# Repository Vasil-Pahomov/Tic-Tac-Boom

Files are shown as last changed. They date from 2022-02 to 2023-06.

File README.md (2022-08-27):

# Tic-Tac-Boom
Аппаратная реализация игры Тик Так Бумм. Дополнительно реализован таймер на 1 минуту, полезный в некоторых играх, например "Скажи иначе" (Alias)

# Использование
Короткое нажатие кнопки запускает таймер, длинное - "бомбу" для Тик Так Бумм.

# Схема
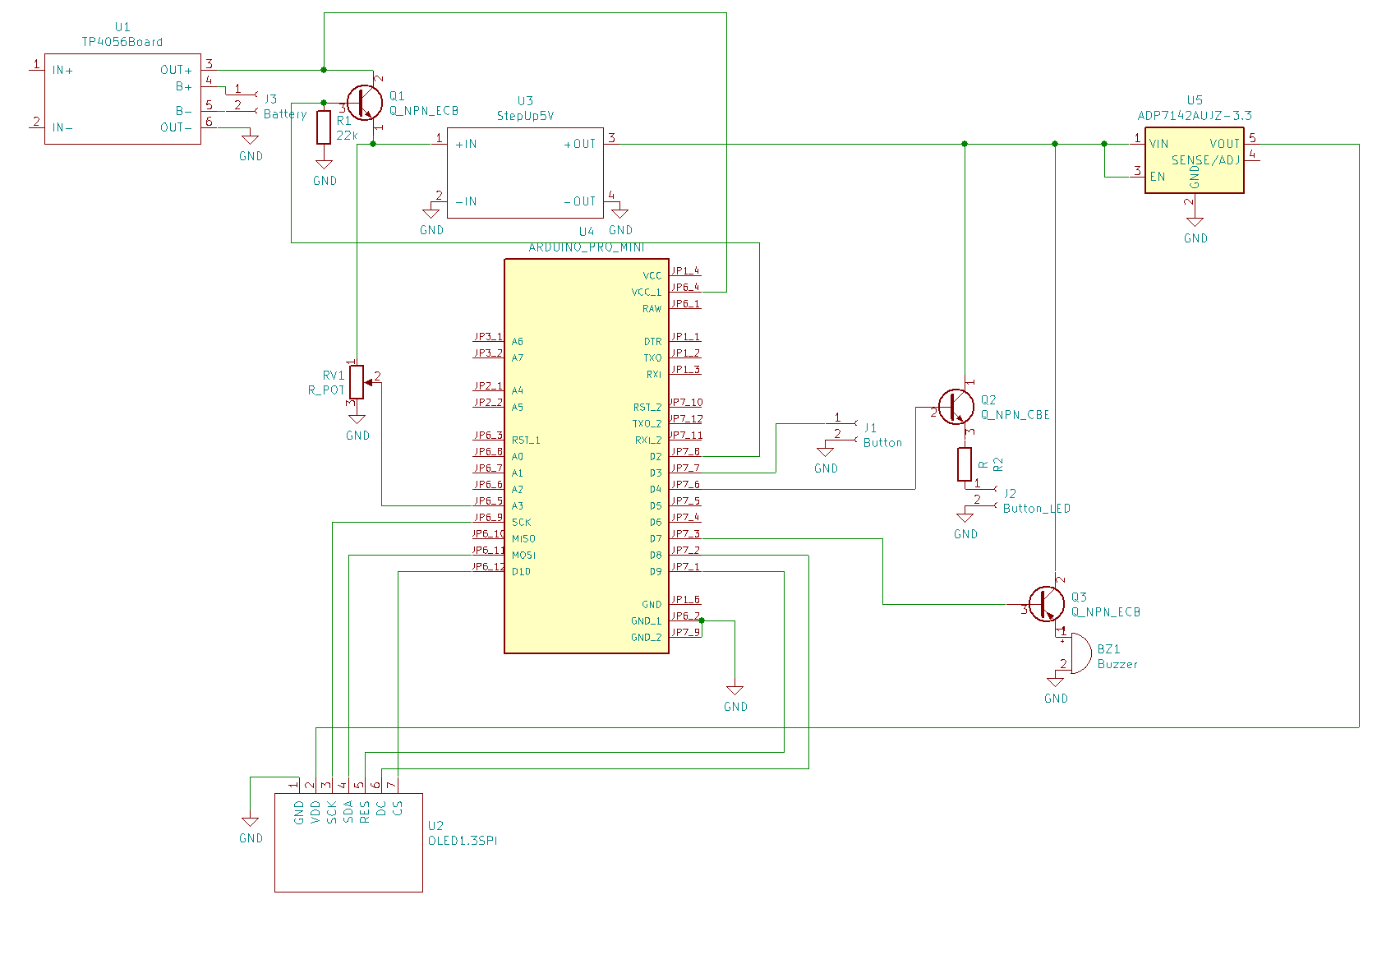
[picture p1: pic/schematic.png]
схема


# Компоненты
## Контроллер
В проекте использована "китайская" плата Arduino Pro Mini, переведённая в режим тактирования от внутреннего RC-генератора (отличная статья: https://tsibrov.blogspot.com/2018/12/arduino-internal-rc.html). Из платы нужно выпаять стабилизатор напряжения и светодиод питания (https://alexgyver.ru/lessons/power-sleep/)
Можно просто выпаять стабилизатор и светодиод, но тогда в режиме ожидания аккумулятор будет выжираться гораздо быстрее.
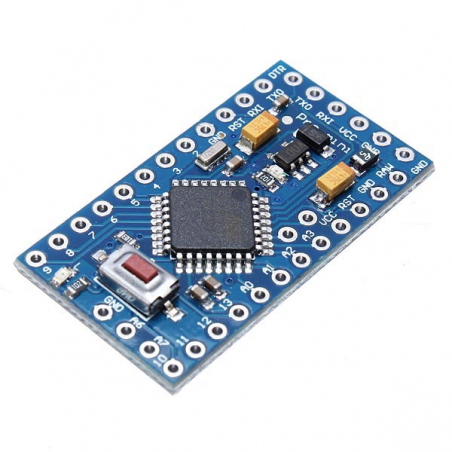
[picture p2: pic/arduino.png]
контроллер


## Экран
Широко распространённый OLED-экран 1.3 дюйма 128x64 точки с интерфейсом SPI.
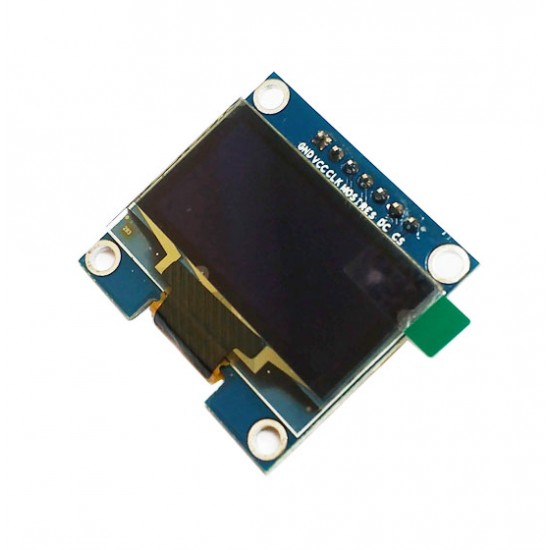
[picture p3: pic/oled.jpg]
экран


## Плата защиты/заряда аккумулятора
"Народная" плата на TP4056
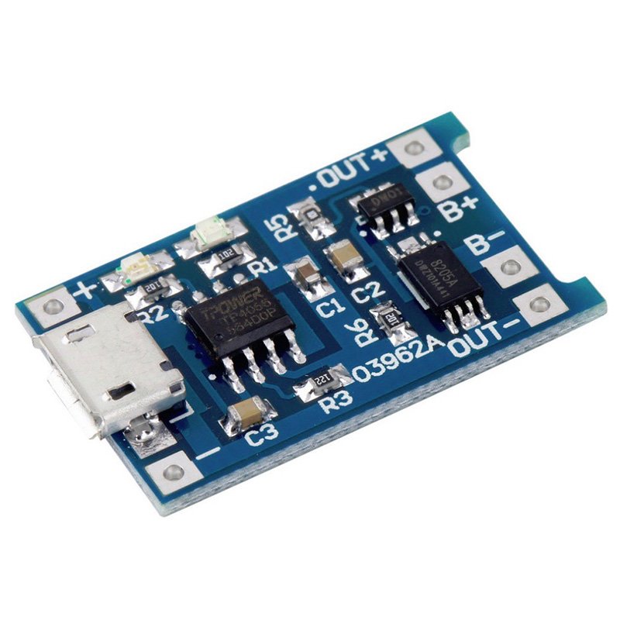
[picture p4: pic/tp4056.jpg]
защита/заряд


## Плата повышающего преобразователя напряжения до 5V
Лежала в старых запасах. Из платы пришлось выпаять разъём USB и подрезать её. Сейчас есть более миниатюрные варианты, можно использовать их.
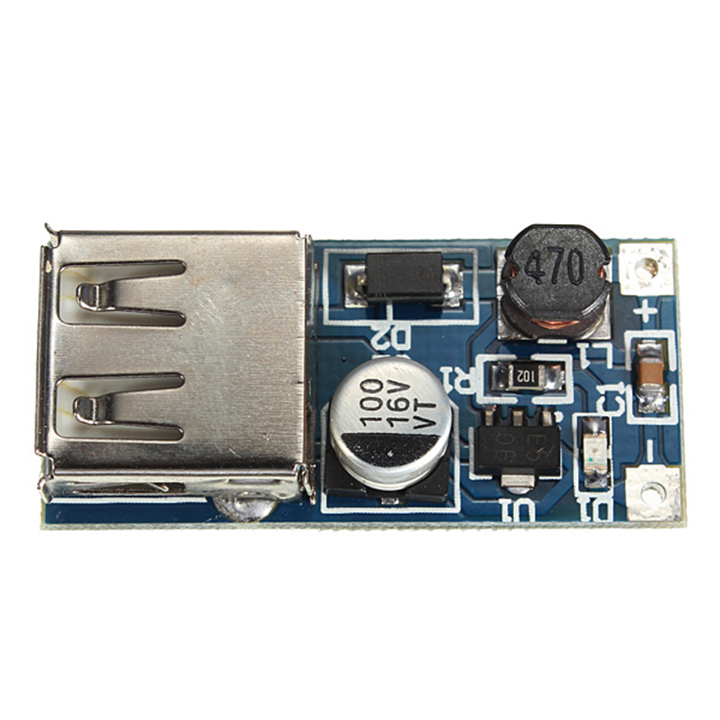
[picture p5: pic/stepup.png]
повышайка


## Кнопка, динамик, остальные элементы
Могут быть любыми. Кнопку лучше искать со встроенным светодиодом - выгдядит эффектнее

# Конструкция
Корпус сделал из двух половинок - каждая из отрезанной от пластиковой бутылки части. Внутри жёсткий каркас образуют круглая плата и вставленный перпендикулярно круг из 3мм оргстекла с вырезами под кнопку и динамик. Кнопка вклеена в каркас, т.к. корпус слишком мягкий и проседал бы при нажатиях.
Не могу сказать, что очень удачная, поэтому не буду рекомендовать к повторению. Проект kicad со схемой и печатной платой есть в папке kicad, можно взять на за основу. 
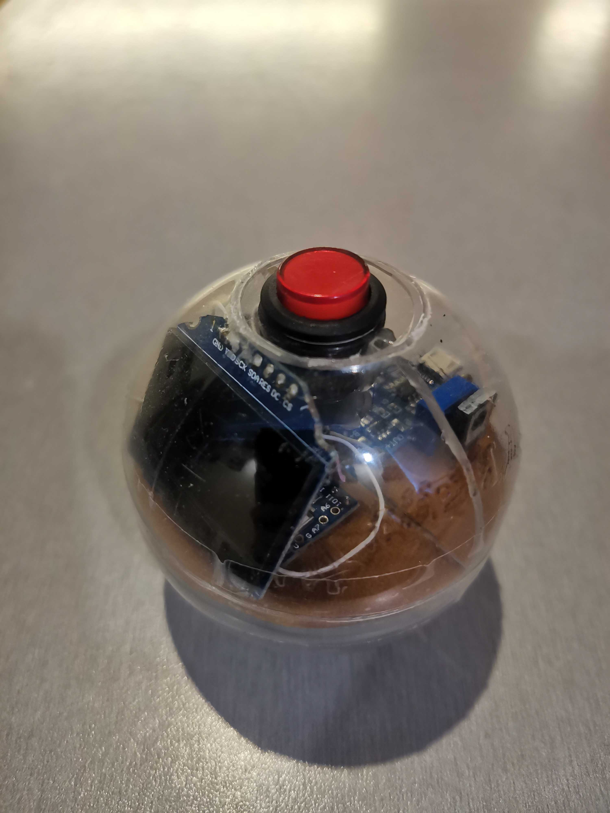
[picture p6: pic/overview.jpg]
общий вид


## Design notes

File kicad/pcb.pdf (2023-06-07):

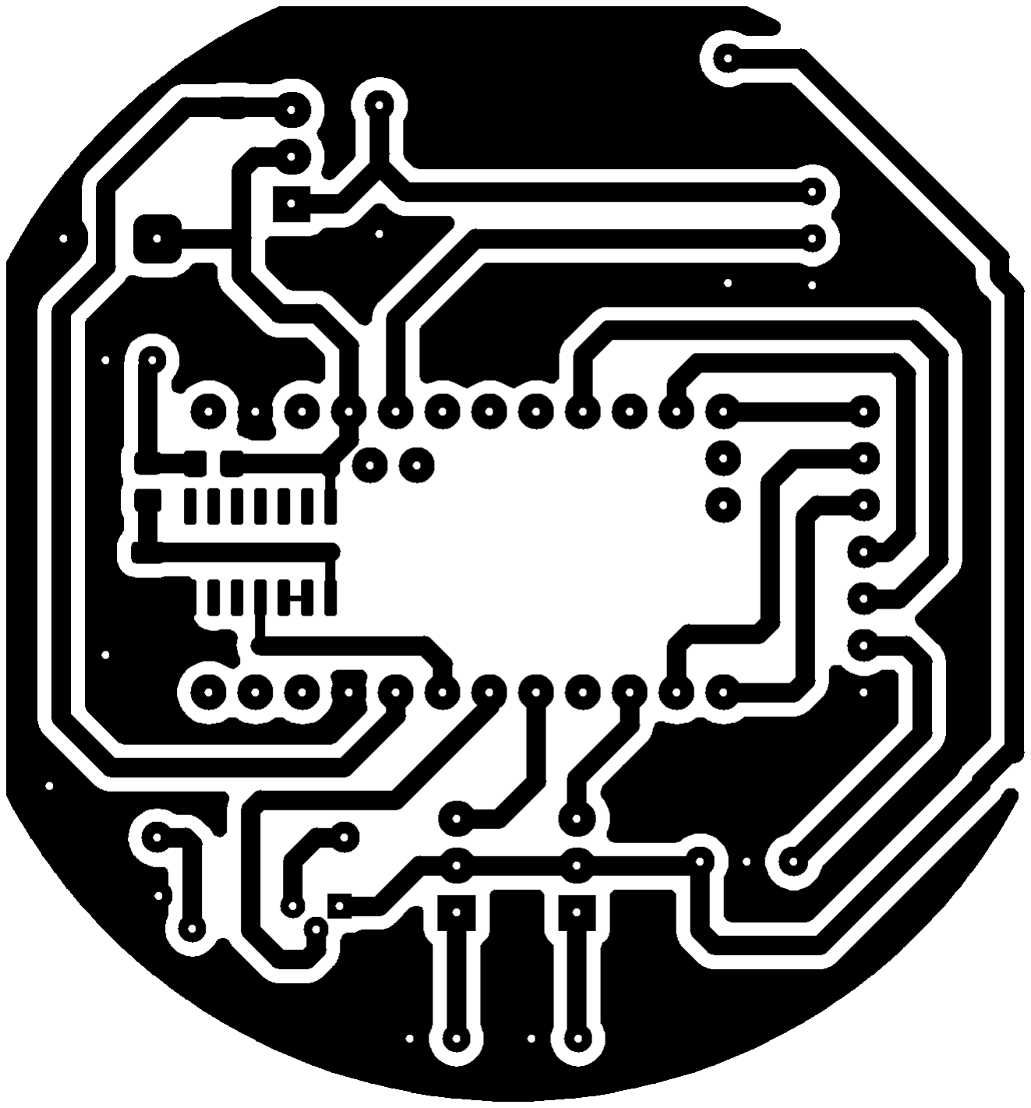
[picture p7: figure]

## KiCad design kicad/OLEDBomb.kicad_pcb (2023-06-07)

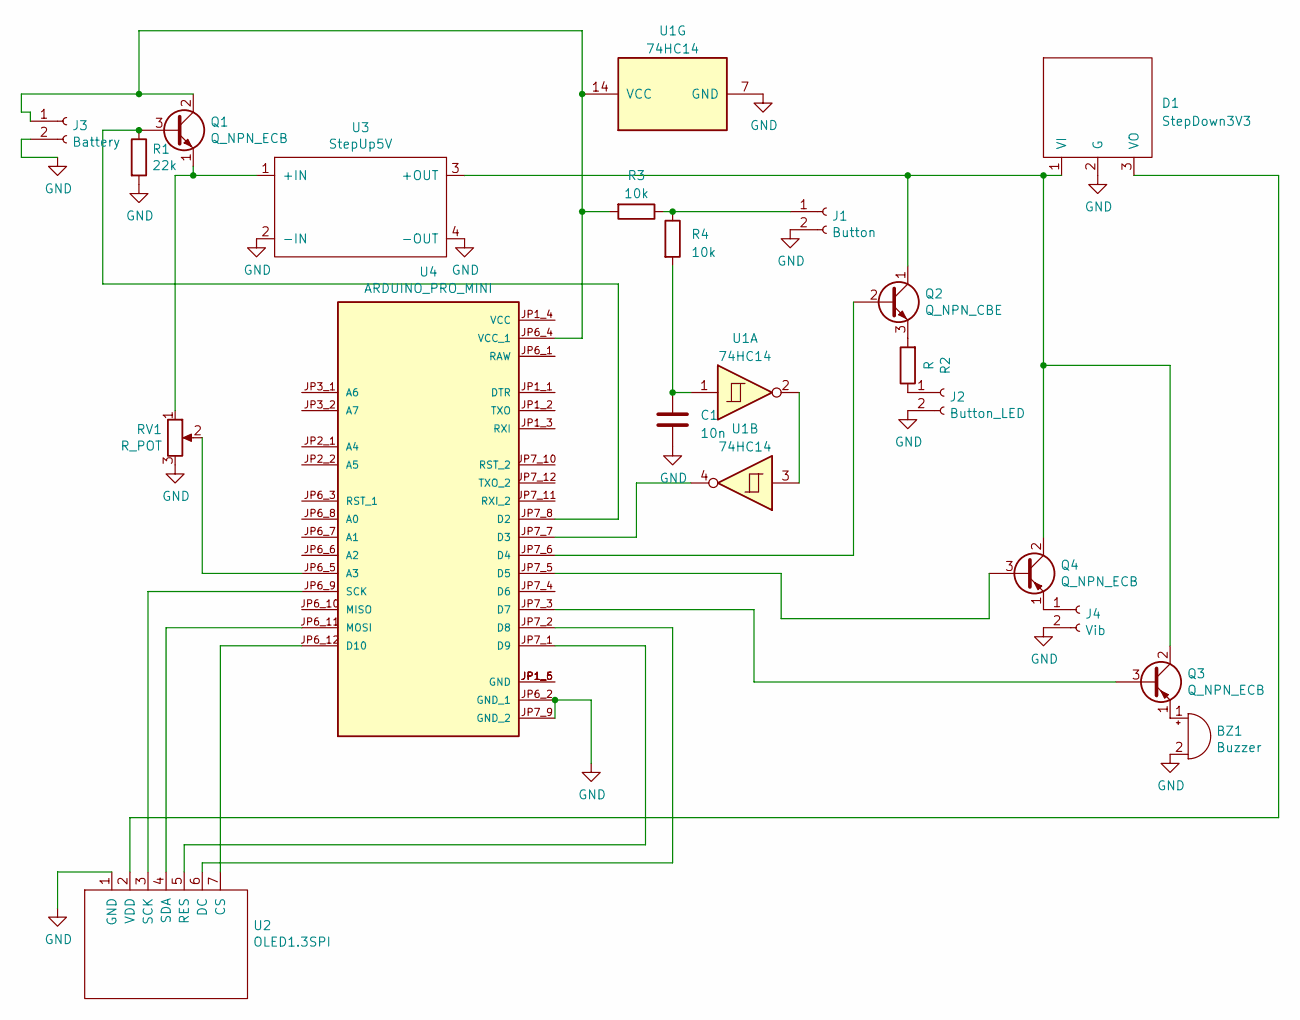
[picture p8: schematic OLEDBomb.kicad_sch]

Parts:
BZ1: Buzzer; TestPoint_2Pads_Pitch2.54mm_Drill0.8mm
C1: 10n; C_1206_3216Metric
D1: StepDown3V3
J1: Button; TestPoint_2Pads_Pitch2.54mm_Drill0.8mm
J2: Button_LED; TestPoint_2Pads_Pitch2.54mm_Drill0.8mm
J3: Battery; TestPoint_2Pads_Pitch5.08mm_Drill1.3mm
J4: Vib; TestPoint_2Pads_Pitch2.54mm_Drill0.8mm
Q1: Q_NPN_ECB; TO-220F-3_Vertical
Q2: Q_NPN_CBE; TO-92
Q3, Q4: Q_NPN_ECB; TO-220-3_Vertical
R1: 22k; R_0805_2012Metric_Pad1.20x1.40mm_HandSolder
R2: R; R_Axial_DIN0207_L6.3mm_D2.5mm_P10.16mm_Horizontal
R3, R4: 10k; R_0805_2012Metric_Pad1.20x1.40mm_HandSolder
RV1: R_POT; Potentiometer_Bourns_3386C_Horizontal
U1: 74HC14
U2: OLED1.3SPI; PinHeader_1x07_P2.54mm_Vertical
U3: StepUp5V
U4: ARDUINO_PRO_MINI; MODULE_ARDUINO_PRO_MINI_NO_PROG_PING; PARTREV N/A

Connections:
GND: BZ1.2 (+), C1.1, D1.2 (G), J1.2, J2.2, J3.2, J4.2, R1.2, RV1.3, U1.7 (GND), U2.1 (GND), U3.2 (-IN), U3.4 (-OUT), U4.JP6_2 (GND_1), U4.JP7_9 (GND_2)
unnamed: BZ1.1 (-), Q3.1 (E)
unnamed: C1.2, R4.2, U1.1
unnamed: D1.1 (VI), Q2.1 (C), Q3.2 (C), Q4.2 (C), U3.3 (+OUT)
unnamed: D1.3 (VO), U2.2 (VDD)
unnamed: J1.1, R3.1, R4.1
unnamed: J2.1, R2.1
unnamed: J3.1, Q1.2 (C), R3.2, U1.14 (VCC), U4.JP6_4 (VCC_1)
unnamed: J4.1, Q4.1 (E)
unnamed: Q1.3 (B), R1.1, U4.JP7_8 (D2)
unnamed: Q1.1 (E), RV1.1, U3.1 (+IN)
unnamed: Q2.2 (B), U4.JP7_6 (D4)
unnamed: Q2.3 (E), R2.2
unnamed: Q3.3 (B), U4.JP7_3 (D7)
unnamed: Q4.3 (B), U4.JP7_5 (D5)
unnamed: U1.2, U1.3
unnamed: U2.7 (CS), U4.JP6_12 (D10)
unnamed: U2.6 (DC), U4.JP7_2 (D8)
unnamed: U2.5 (RES), U4.JP7_1 (D9)
unnamed: U2.3 (SCK), U4.JP6_9 (SCK)
unnamed: U2.4 (SDA), U4.JP6_11 (MOSI)
unnamed: RV1.2, U4.JP6_5 (A3)
unnamed: U1.4, U4.JP7_7 (D3)

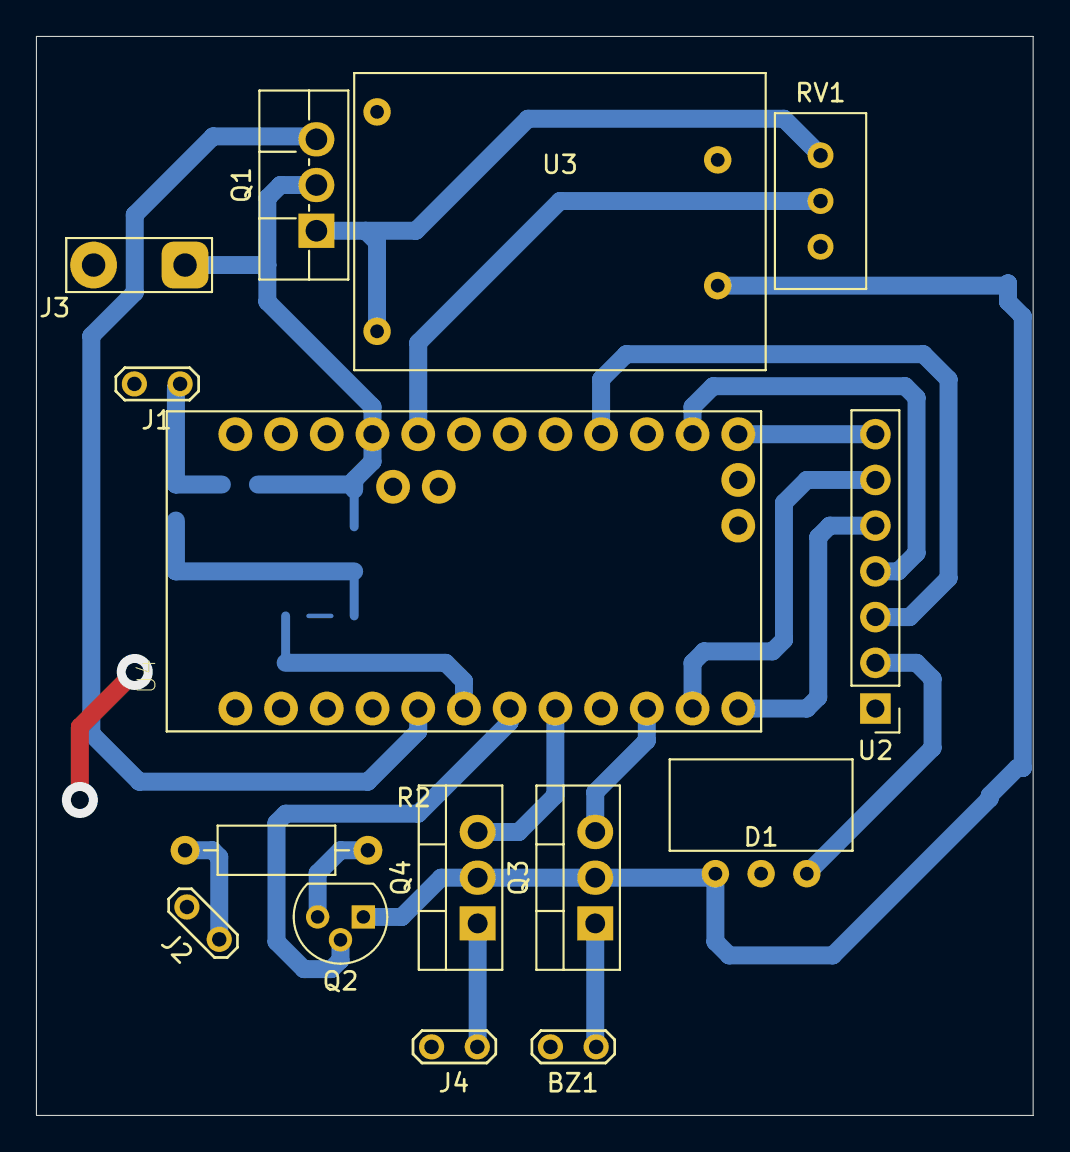
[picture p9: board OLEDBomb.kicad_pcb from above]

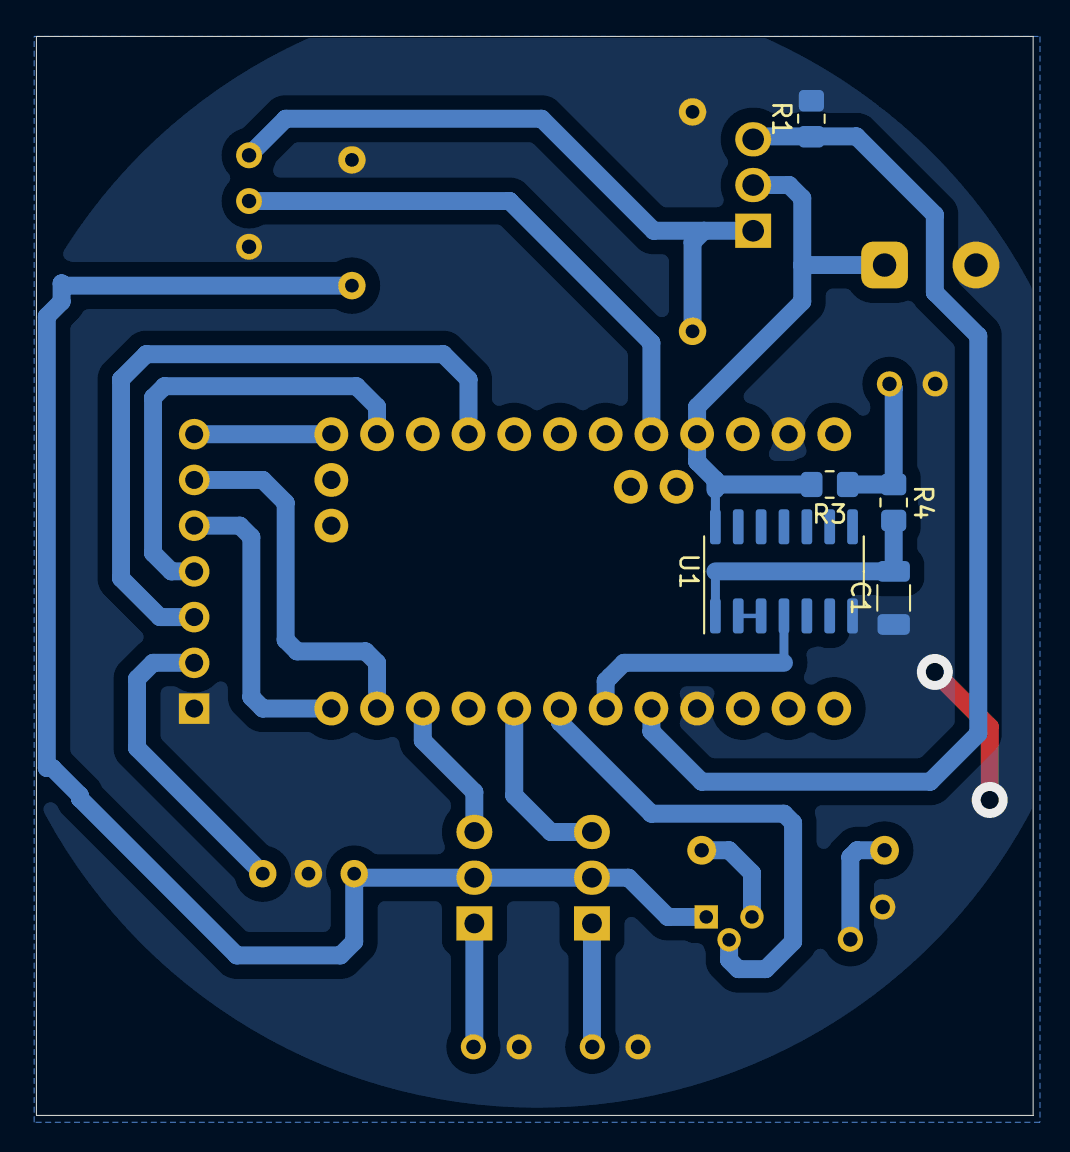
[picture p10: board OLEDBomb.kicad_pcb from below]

Board: 2 copper layers, 55.4 x 59.9 mm, 20 parts (5 on the bottom side), 23 nets.

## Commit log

2022-08-27 Locking/unlocking by triple button press
2023-06-07 Added English syllables Added ability to remove syllable limitations (no ellipses and the beginning and/or end of syllables) Added settings (hold the button): rus/eng syllables for bomb, small/big te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
    [OLEDBomb.kicad_pcb, OLEDBomb.sch]
2023-06-08 Missing Kicad files
    [OLEDBomb-r.sch, OLEDBomb.kicad_sch]
2024-02-10 Improve button handling
